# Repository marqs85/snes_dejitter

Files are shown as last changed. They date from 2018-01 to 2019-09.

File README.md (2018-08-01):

NES/SNES 240p de-jitter mod
==============

snes_dejitter is a mod board which eliminates sync jitter of NES/SNES 240p modes. Technical description and discussion is found on [this](https://shmups.system11.org/viewtopic.php?f=6&t=61285) thread.

Requirements for building the board and CPLD firmware
--------------------------------------------------------
* Hardware
  * [PCB](https://oshpark.com/shared_projects/NkuS1ju6) + [parts](pcb/bom/snes_dejitter.ods)

* Software
  * [Altera Quartus II version 13.0sp1 with MAX7000 support](http://dl.altera.com/13.0sp1/?edition=web)
  * [pof2jed](http://www.microchip.com/design-centers/programmable-logic/spld-cpld/tools/software/pof2jed) conversion tool
  * [ATMISP](http://www.microchip.com/design-centers/programmable-logic/spld-cpld/tools/software/atmisp) software
  * [WINE](https://www.winehq.org/) (if Windows OS is not used)

Requirements for flashing CPLD firmware
--------------------------------------------------------
* Hardware
  * OpenOCD supported JTAG programmer (e.g. FT2232 based)

* Software
  * [OpenOCD](http://openocd.org/)
  * Telnet client

CPLD image build procedure
--------------------------------------------------------

**NOTE:** Only needed when building a custom firmware. Pre-built images can be found under output_files/ on master and nes-fix (recommended for NES/FC) branches.

1. Open the project file in Quartus, and run compilation

2. Convert MAX7000 targeted POF object file into JEDEC file suitable for 1502AS via winpof2jed.exe:
~~~~
1. Select .pof file from previous step as input file
2. Select 1502AS as device
3. Change the following options:
  * Reduce MC power -> On
  * Open Collector -> Off
  * JTAG mode -> On
  * Slew rate -> Slow
4. Click "Run"
~~~~
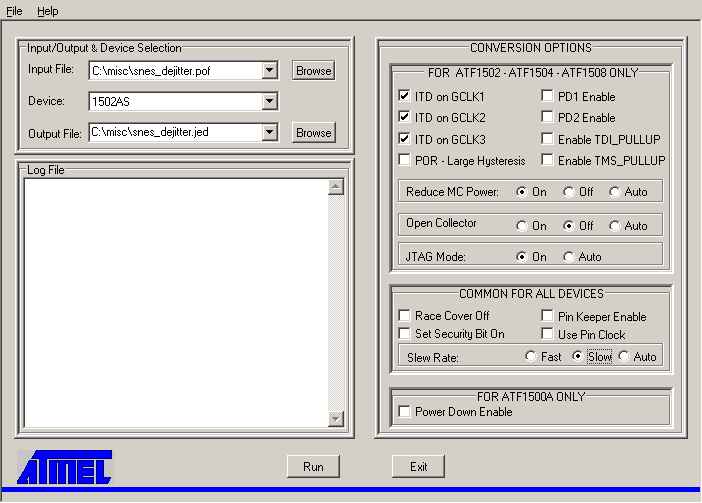
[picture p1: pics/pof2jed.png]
pof2jed


3. Convert JED to SVF via ATMISP:
~~~~
1. Create a new device chain via File->New
2. Set number of devices to 1
3. Set device to ATF1502AS
4. Set JTAG instruction to "Program/Verify"
5. Select .jed file from previous step as JEDEC file
6. Click "OK"
7. Tick "Write SVF file" and click "Run"
~~~~
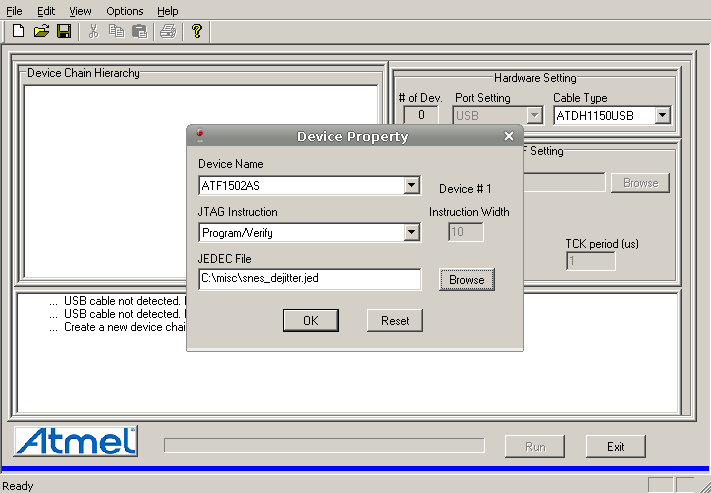
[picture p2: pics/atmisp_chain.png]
atmisp1

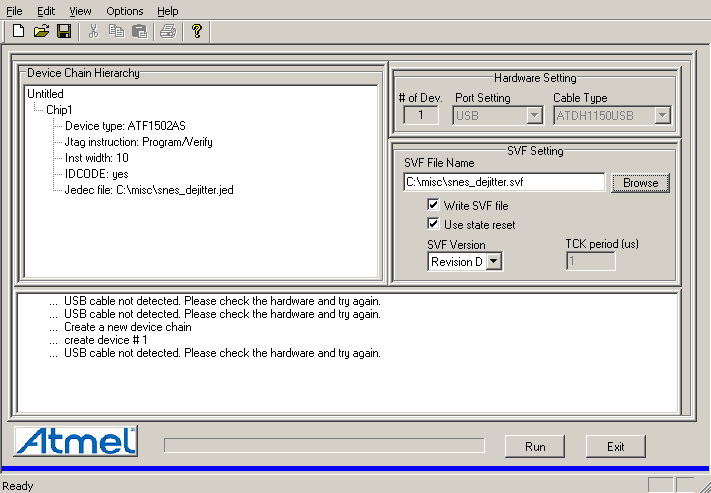
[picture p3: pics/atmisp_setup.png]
atmisp1


Board flashing
--------------------------------------------------------
The board can be flashed using any OpenOCD supported JTAG programmer that supports 3.3V-5V IO signal level (TCK, TMS and TDI are TTL inputs with 10k pull-downs). If 3.3V IO is used, JP4 (on v1.3 PCB) should be closed which clamps TDO output to 3.3V. A standalone snes_jitter board is flashed by hooking all of its 6 JTAG header pins to respective pins of the programmer/cable, and by running flash procedure specified below. After the board has been installed to NES/SNES, firmware can be subsequently updated, but in this method 5V pin of the JTAG connector MUST be left disconnected, and programming needs to be done while NES/SNES is powered on (without a game is ok). The update procedure is similar in both cases:

1. Create openocd.conf that matches your JTAG programmer. A configuration file for FT2232-based programmers is found in installation/openocd-ft2232.conf, and it uses following standard pinout for data signals:

Board pin | Programmer pin
--------- | -------------
TCK       | ADBUS0
TMS       | ADBUS3
TDI       | ADBUS1
TDO       | ADBUS2

2. After hooking up JTAG cable, initiate JTAG connection:
~~~~
openocd -f openocd.conf
~~~~
3. OpenOCD auto-probing should report a TAP controller with id 0x0150203f - if not, check connections and configuration. When successful, open another terminal to interact with openocd and program the chip:
~~~~
telnet localhost 4444
> svf <full_path_to_svf_file>
~~~~
4. The programming procedure should finish with no error, after which you can finish installation by powering off hardware and disconnecting the programmer.

Installation
--------------------------------------------------------
General descriptions on board pins are in table below. Model-specific installation instructions are added to separate <a href="installation/">subdirectories</a>.

Board pin  | Description
---------- | -------------
CSYNC_i    | TTL C-sync signal from the console
MCLK_EXT_i | External clock input. Used only in PAL mode, not needed in pure NTSC installations.
CLK_SEL_i  | Master clock source selection (0=internal/NTSC, 1=external/PAL). In PAL mode, MCLK and CSYNC are bypassed to output. Pin is pulled low internally, so it can be left disconnected in pure NTSC installations. Connected to PALMODE in multiregion installations. Can be forced high by bridging JP1 (pre-1.2 boards only), but must never be done if the pin is wired to console.
MCLK_o     | Clock output. An optional voltage divider (R13,R14 / JP2) can be used to reduce output level from ~4Vpp to ~3Vpp, see model-specific instructions for more details.
CSYNC_o    | C-sync output (~2.5Vpp unterminated, ~1.1Vpp into 75ohm termination) to an isolated multi-AV pin. Driver circuit is identical to SHVC-CPU-01. JP3 connects optional 330pF output capacitor that may not be present on console mainboard (not strictly needed, reduces potential noise at the price of less sharp transition time), see model-specific instructions for more details.

Jumper  | Description
------- | -------------
JP1     | Forces CLK_SEL_i high. Removed on v1.2 since it was mostly for debugging purposes.
JP2     | Enables MCLK_o voltage divider. Recommended for NES installations to ensure signal level is safe for NESRGB.
JP3     | Connects optional 330pF output capacitor on CSYNC_o.
JP4     | Enable TDO voltage clamp. Recommended if board is flashed with a 3.3V programmer.

PCB revision history
--------------------------------------------------------
### v1.3
* change (R9,R10) voltage divider values
* replace TDO voltage divider with an optional zener clamp (selectable via JP4)
* add R15 pulldown to prevent floating input pin

### v1.2
* remove JP1
* add JP2 and JP3 to easily support different setups

### v1.1
* change R14 value
* change JTAG connector

### v1.0
* first revision

FAQ
--------------------------------------------------------
### Can I buy the board pre-assembled / pre-installed
* VGP [store](https://www.videogameperfection.com/products/snes-jitter-kit/) offers pre-assembled boards with optional installation service.

### Can I flash the board with USB Blaster?
* USB Blaster is compatible with OpenOCD, but you have to check your programmer details (official/clone, 5V compatibility) and hook up and configure it accordingly. Official USB Blaster has fixed 6MHz TCK frequency which is probably too high for the board, so USB Blaster II and clones are more likely to work. None of the USB Blasters supply voltage on the board, but instead require connection from the board's supply to Vcc(TRGT) pin of the debug connector. You must thus power the board externally and connect 5V to Vcc(TRGT) (make sure your programmer supports 5V operation!). Some clones also require hacks on OpenOCD to operate correctly, see the [thread](https://shmups.system11.org/viewtopic.php?f=6&t=61285) for more details.

### Which other programmers can I use?
* OpenOCD supports a wide range of [debug adapters](http://openocd.org/doc/html/Debug-Adapter-Hardware.html). Several people also have programmed their boards using a Raspberry Pi. Instructions and tools for RPI can be found on the [thread](https://shmups.system11.org/viewtopic.php?f=6&t=61285).

### Does the mod change game speed in any way?
* Yes, but in very minimal way - in 1 hour of gameplay a de-jittered system falls less than 2 frames behind a vanilla system.

### Is it possible to disable de-jitter functionality after installation?
* When the board is installed so that MCLK_EXT_i and CLK_SEL_i are not used, a simple bypass can be added without firmware modifications. To do that, connect MCLK_EXT_i to CPLD pin 34 (MCLK_XTAL_o) and add a ON-OFF switch that connects MCLK_SEL_i to 5V.

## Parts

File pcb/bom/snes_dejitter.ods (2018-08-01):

Id | Designator | Package | Quantity | Designation | Supplier and ref | Alt. Supplier
1 | C1 | SM0603_Capa_libcms | 1 | 10u | https://www.digikey.fi/product-detail/en/murata-electronics-north-america/GRM188R60J106ME47D/490-3896-1-ND/965938 | https://www.mouser.fi/ProductDetail/581-06036D106MAT2A
2 | C2,C3,C4,C7 | SM0603_Capa_libcms | 4 | 0.1u | https://www.digikey.fi/product-detail/en/kemet/C0603C104K9RAC7867/399-15351-1-ND/7386749 | https://www.mouser.fi/ProductDetail/77-VJ0603Y104JXJPBC
3 | C5,C6 | SM0603_Capa_libcms | 2 | 12p | https://www.digikey.fi/product-detail/en/yageo/CC0603FRNPO9BN120/311-3885-1-ND/8024974 | https://www.mouser.fi/ProductDetail/77-VJ0603A120FXQCBC
4 | C8 | SM0603_Capa_libcms | 1 | 330p | https://www.digikey.fi/product-detail/en/murata-electronics-north-america/GCM1885C1H331FA16D/490-16420-1-ND/7363402 | https://www.mouser.fi/ProductDetail/80-C0603C331J5G
5 | Q1 | SOT-23_Handsoldering | 1 | 2SC2412 | https://www.digikey.fi/product-detail/en/rohm-semiconductor/2SC2412KT146R/2SC2412KT146RCT-ND/650652 | https://www.mouser.fi/ProductDetail/ROHM-Semiconductor/2SC2412KT146R
6 | R1,R2,R3,R6,R15 | SM0603_Resistor_libcms | 5 | 10k | https://www.digikey.fi/product-detail/en/susumu/RR0816P-103-D/RR08P10.0KDCT-ND/432748 | https://www.mouser.fi/ProductDetail/754-RR0816P-103D
7 | R8,R9 | SM0603_Resistor_libcms | 2 | 1k | https://www.digikey.fi/product-detail/en/yageo/RC0603FR-071KL/311-1.00KHRCT-ND/729790 | https://www.mouser.fi/ProductDetail/754-RR0816P-102D
8 | R10 | SM0603_Resistor_libcms | 1 | 5.6k | https://www.digikey.fi/product-detail/en/bourns-inc/CR0603-FX-5601ELF/CR0603-FX-5601ELFCT-ND/4247814 | https://www.mouser.fi/ProductDetail/Bourns/CR0603-FX-5601ELF
9 | R7 | SM0603_Resistor_libcms | 1 | 1M | https://www.digikey.fi/product-detail/en/yageo/AC0603FR-071ML/311-1MLDCT-ND/2828141 | https://www.mouser.fi/ProductDetail/603-RT0603FRE071ML
10 | R11,R14 | SM0603_Resistor_libcms | 2 | 300 | https://www.digikey.fi/product-detail/en/yageo/RC0603FR-07300RL/311-300HRCT-ND/726133 | https://www.mouser.fi/ProductDetail/754-RR0816P-301D
11 | R12 | SM0603_Resistor_libcms | 1 | 100 | https://www.digikey.fi/product-detail/en/vishay-dale/CRCW0603100RFKEA/541-100HCT-ND/1179695 | https://www.mouser.fi/ProductDetail/594-MCT06030C1000FP5
12 | R4,R13 | SM0603_Resistor_libcms | 2 | 39 | https://www.digikey.fi/product-detail/en/vishay-dale/CRCW060339R0FKEA/541-39.0HCT-ND/1179647 | https://www.mouser.fi/ProductDetail/603-RT0603DRE0739RL
13 | Y1 | Crystal_HC49-U_Vertical | 1 | 21.477272MHz | https://www.digikey.fi/products/en?keywords=HC49US-21.47727MABJ-UB | https://www.mouser.fi/ProductDetail/695-HC49US-214-U
14 | U1 | TQFP-44_10x10mm_Pitch0.8mm_Handsoldering | 1 | ATF1502AS-7AX44 | https://www.digikey.fi/products/en?keywords=ATF1502AS-7AX44 | https://www.mouser.fi/ProductDetail/556-AF1502AS7AX44
15 | J1 | JTAG_Header_Angled_1x06_Pitch2.54mm | 1 | JTAG_CONN | https://www.digikey.fi/product-detail/en/sullins-connector-solutions/PPPC061LGBN-RC/S5481-ND/775939
16 | D1 | SOD-323_Handsoldering | 1 | Zener_3v3 | https://www.digikey.fi/product-detail/en/diodes-incorporated/MMSZ5226BS-7-F/MMSZ5226BS-FDICT-ND/804906 | https://www.mouser.fi/ProductDetail/Diodes-Incorporated/MMSZ5226BS-7-F

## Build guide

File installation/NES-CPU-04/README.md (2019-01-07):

NES-CPU-04 installation guide
==============

(from [Retro Modding Wiki](https://www.retromodwiki.com/wiki/NES_dejitter_mod))

Steps

1. Remove C44, C45, and X1 from the NES motherboard
2. Connect a jumper wire between the pads of C44 and C45 as illustrated below.
3. Short JP2 and JP3 on snes_dejitter board
4. Cover copper areas on the bottom of snes_dejitter with electrical tape
5. Attach snes_dejitter on the bottom of NESRGB adapter board via double-sided adhesive tape
6. Connect 5V, GND and CSYNC_i to respective pads on NESRGB board (CSYNC_i -> CS# with NESRGB jumper J8 open)
7. Connect MCLK_o as shown in the picture and CSYNC_o to AV connector (possibly via 470ohm series resistor depending on your cable and preference). For MCLK_o, it is recommended to use a coax cable of which shield is connected to nearest GND in both ends
8. If the board has been flashed with default firmware, update it to [NES-tailored svf](https://github.com/marqs85/snes_dejitter/raw/nes-fix/output_files/snes_dejitter.svf) from nes-fix branch

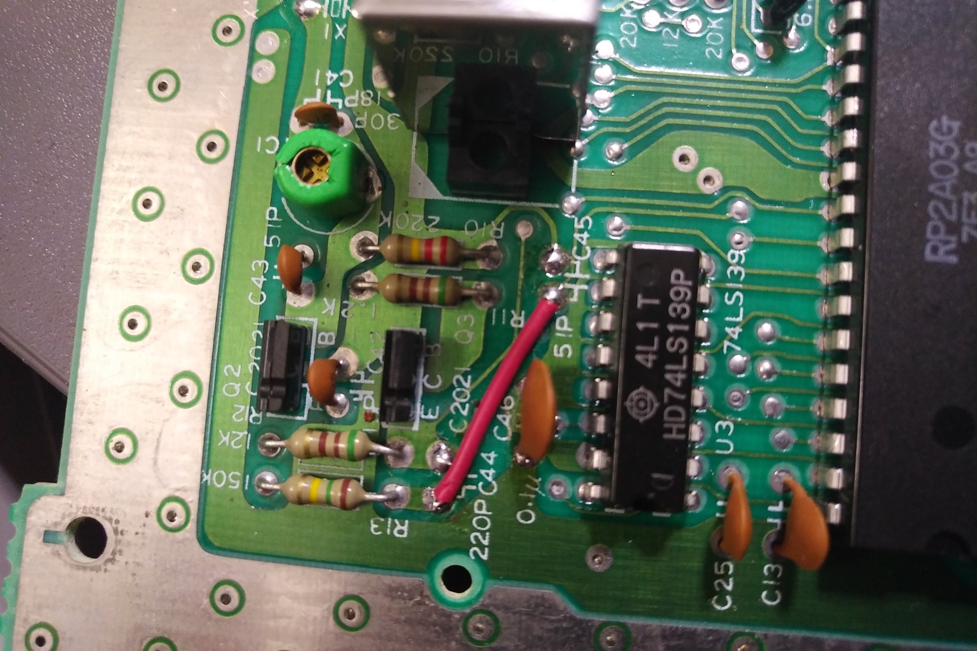
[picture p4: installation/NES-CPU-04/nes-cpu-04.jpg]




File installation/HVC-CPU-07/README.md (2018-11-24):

HVC-CPU-07 installation guide
==============

Steps

1. Desolder C4, C9 and (optionally) XTAL from Famicom mainboard
2. Add a jumper wire between C4 & C9 pads on CPU/PPU sides as shown in the picture below (ignore wires outside of red highlight circle)
3. Short JP2 and JP3 on snes_dejitter board
4. Cover copper areas on the bottom of snes_dejitter with electrical tape
5. Attach snes_dejitter on the bottom of NESRGB adapter board via double-sided adhesive tape
6. Connect 5V, GND and CSYNC_i to respective pads on NESRGB board (CSYNC_i -> CS# with NESRGB jumper J8 open)
7. Connect MCLK_o as shown in the picture and CSYNC_o to AV connector (possibly via 470ohm series resistor depending on your cable and preference). For MCLK_o, it is recommended to use a coax cable of which shield is connected to nearest GND in both ends
8. If the board has been flashed with default firmware, it's recommended to update it to [NES-tailored svf](https://github.com/marqs85/snes_dejitter/raw/nes-fix/output_files/snes_dejitter.svf) from nes-fix branch

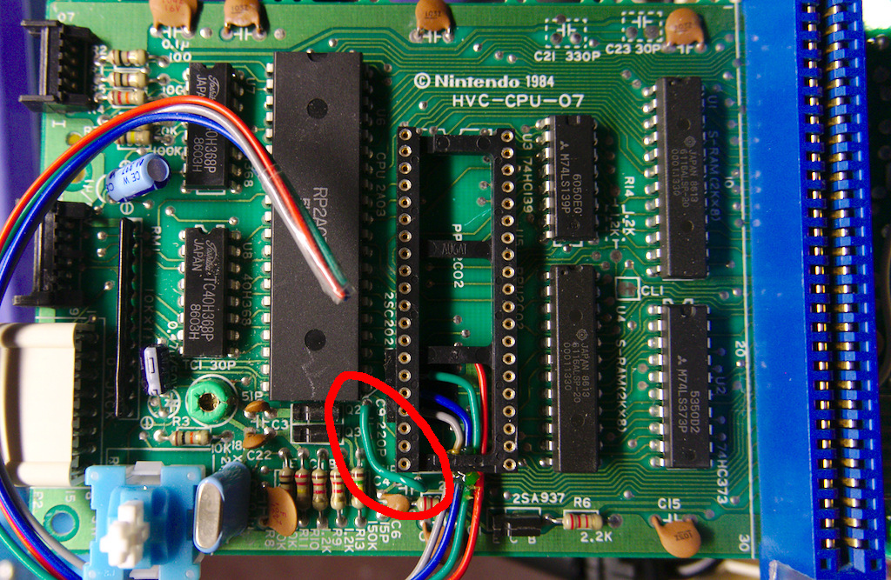
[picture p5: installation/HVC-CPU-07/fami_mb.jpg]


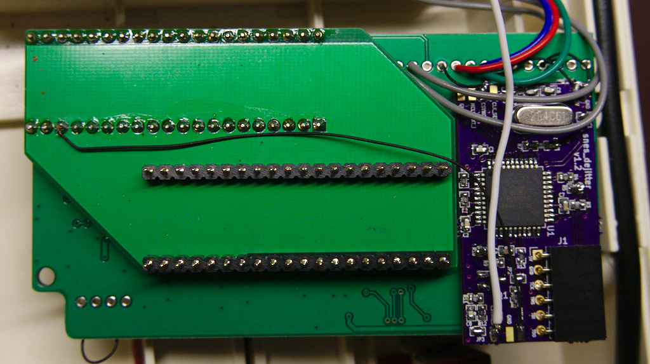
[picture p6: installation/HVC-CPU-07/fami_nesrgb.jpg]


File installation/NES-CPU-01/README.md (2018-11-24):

NES-CPU-01 installation guide
==============

(from [Retro Modding Wiki](https://www.retromodwiki.com/wiki/NES_dejitter_mod))

Steps

1. Remove C44, C45, and X1 from the NES motherboard
2. Connect a jumper wire between the outside pads of C44 and C45
3. Short JP2 and JP3 on snes_dejitter board
4. Cover copper areas on the bottom of snes_dejitter with electrical tape
5. Attach snes_dejitter on the bottom of NESRGB adapter board via double-sided adhesive tape
6. Connect 5V, GND and CSYNC_i to respective pads on NESRGB board (CSYNC_i -> CS# with NESRGB jumper J8 open)
7. Connect MCLK_o as shown in the picture and CSYNC_o to AV connector (possibly via 470ohm series resistor depending on your cable and preference). For MCLK_o, it is recommended to use a coax cable of which shield is connected to nearest GND in both ends
8. If the board has been flashed with default firmware, update it to [NES-tailored svf](https://github.com/marqs85/snes_dejitter/raw/nes-fix/output_files/snes_dejitter.svf) from nes-fix branch







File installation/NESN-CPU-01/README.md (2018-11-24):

NESN-CPU-01 installation guide
==============

(from [Retro Modding Wiki](https://www.retromodwiki.com/wiki/NES_dejitter_mod))

Steps

1. Remove C10 and X1 from the NES motherboard
2. Short JP2 and JP3 on snes_dejitter board
3. Cover copper areas on the bottom of snes_dejitter with electrical tape
4. Attach snes_dejitter on the bottom of NESRGB adapter board via double-sided adhesive tape
5. Connect 5V, GND and CSYNC_i to respective pads on NESRGB board (CSYNC_i -> CS# with NESRGB jumper J8 open)
6. Connect MCLK_o as shown in the picture and CSYNC_o to AV connector (possibly via 470ohm series resistor depending on your cable and preference). For MCLK_o, it is recommended to use a coax cable of which shield is connected to nearest GND in both ends
7. If the board has been flashed with default firmware, update it to [NES-tailored svf](https://github.com/marqs85/snes_dejitter/raw/nes-fix/output_files/snes_dejitter.svf) from nes-fix branch







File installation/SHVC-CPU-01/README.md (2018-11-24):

SHVC-CPU-01 installation guide
==============

Features

* single MCLK provided by snes_dejitter
* de-jittered CSYNC on multi-AV pin 3 (compatible with RGB cables wired to use CSYNC)

Steps

1. Desolder C5, R6 and R25 on SNES mainboard
2. Leave JP3 open on snes_dejitter board (rev v1.0/v1.1: leave C8 unpopulated)
3. Short JP2 on snes_dejitter board (v1.2 and higher revisions only)
4. Cover copper areas on the bottom of snes_dejitter with electrical tape
5. Attach snes_dejitter on the bottom of SNES mainboard via double-sided adhesive tape
6. Connect 5V, GND, CSYNC_i, CSYNC_o and MCLK_o as shown in image below

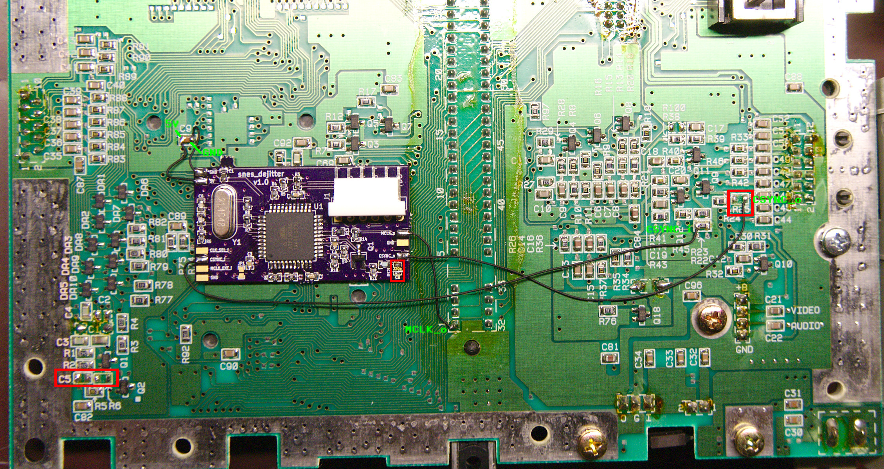
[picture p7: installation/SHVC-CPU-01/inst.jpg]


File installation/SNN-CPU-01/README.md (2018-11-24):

SNN-CPU-01 installation guide
==============

Features

* single MCLK provided by snes_dejitter
* de-jittered CSYNC on multi-AV pin 3 (compatible with RGB cables wired to use CSYNC)

Steps

1. Remove X1 and C3 from SNES mainboard
2. Leave JP2 open and close JP3 on snes_dejitter board (rev v1.0/v1.1: leave R14 unpopulated)
3. Cover copper areas on the bottom of snes_dejitter with electrical tape
4. Attach snes_dejitter on the bottom of SNES mainboard via double-sided adhesive tape
5. Connect 5V, GND and MCLK_o as shown in image below. CSYNC_i can be tapped from pin 7 of S-RGB, and CSYNC_o should be directly wired to pin 3 of multi-AV.

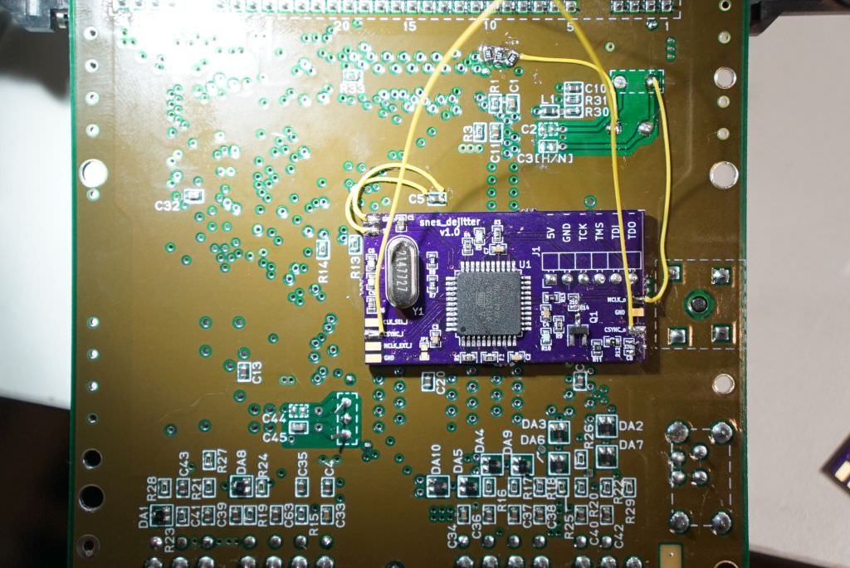
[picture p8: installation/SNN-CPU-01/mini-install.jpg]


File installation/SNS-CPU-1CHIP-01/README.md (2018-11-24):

SNS-CPU-1CHIP-01 installation guide
==============

Features

* single MCLK provided by snes_dejitter
* de-jittered CSYNC on multi-AV pin 3 (compatible with RGB cables wired to use CSYNC)

Steps

1. Remove X1, C3 and R12 from SNES mainboard
2. Leave JP2 and JP3 open on snes_dejitter board (rev v1.0/v1.1: leave C8 and R14 unpopulated)
3. Cover copper areas on the bottom of snes_dejitter with electrical tape
4. Attach snes_dejitter on the bottom of SNES mainboard via double-sided adhesive tape
5. Connect 5V, GND, CSYNC_i, CSYNC_o and MCLK_o as shown in image below

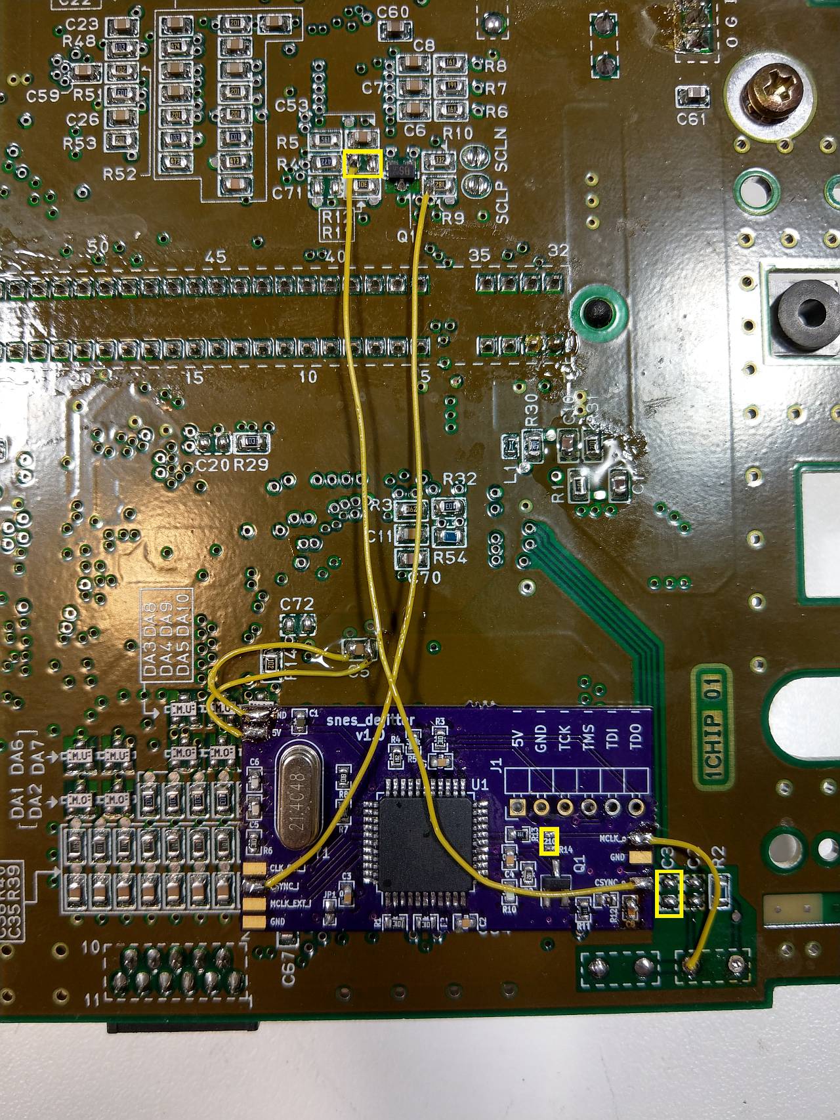
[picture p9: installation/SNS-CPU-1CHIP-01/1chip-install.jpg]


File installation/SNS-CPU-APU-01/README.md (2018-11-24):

SNS-CPU-APU-01 installation guide
==============

Features

* single MCLK provided by snes_dejitter
* de-jittered CSYNC on multi-AV pin 3 (compatible with RGB cables wired to use CSYNC)

Steps

1. Remove R12, R17 and R55 from SNES mainboard
2. Leave JP3 open on snes_dejitter board (rev v1.0/v1.1: leave C8 unpopulated)
3. Short JP2 on snes_dejitter board (v1.2 and higher revisions only)
4. Cover copper areas on the bottom of snes_dejitter with electrical tape
5. Attach snes_dejitter on the bottom of SNES mainboard via double-sided adhesive tape
6. Connect 5V, GND, CSYNC_i, CSYNC_o and MCLK_o as shown in image below

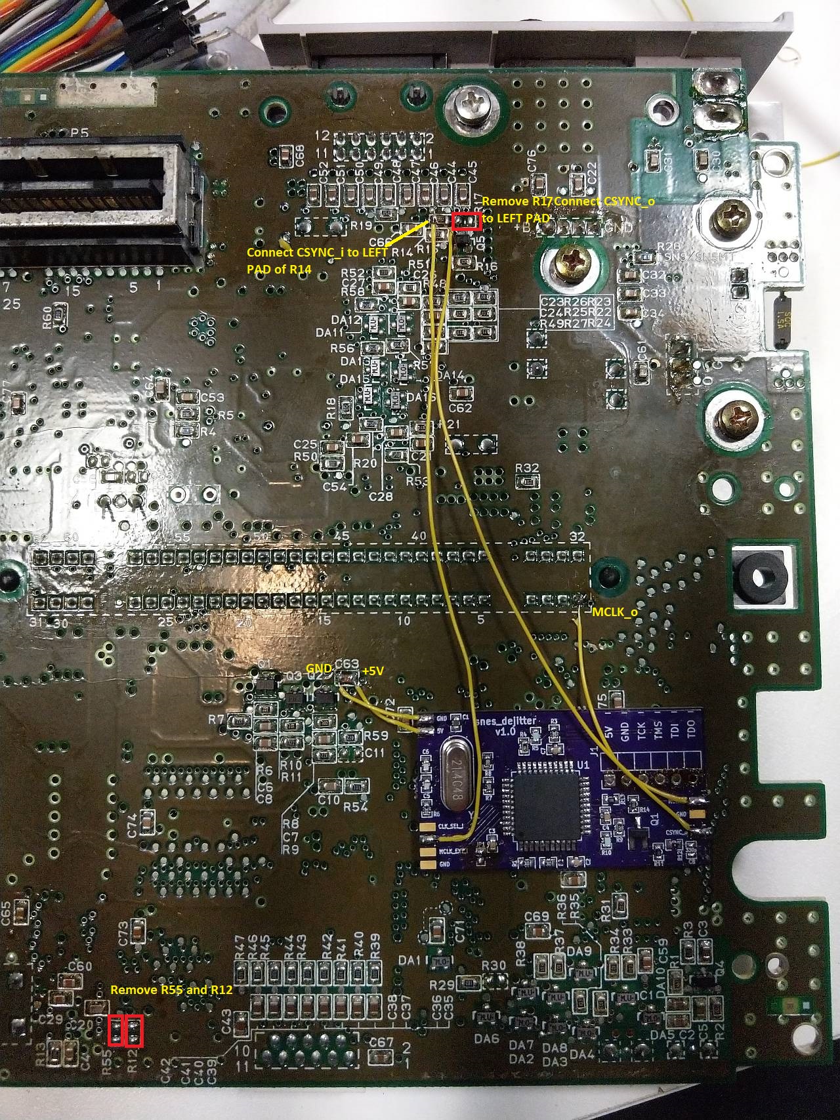
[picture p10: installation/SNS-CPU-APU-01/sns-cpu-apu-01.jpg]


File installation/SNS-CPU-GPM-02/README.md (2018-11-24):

SNS-CPU-GPM-02 installation guide
==============

Features

* single MCLK provided by snes_dejitter
* de-jittered CSYNC on multi-AV pin 3 (compatible with RGB cables wired to use CSYNC)

Steps

1. Remove R4, R5 and R25 from SNES mainboard
2. Leave JP3 open on snes_dejitter board (rev v1.0/v1.1: leave C8 unpopulated)
3. Short JP2 on snes_dejitter board (v1.2 and higher revisions only)
4. Cover copper areas on the bottom of snes_dejitter with electrical tape
5. Attach snes_dejitter on the bottom of SNES mainboard via double-sided adhesive tape
6. Connect 5V, GND, CSYNC_i, CSYNC_o and MCLK_o as shown in image below

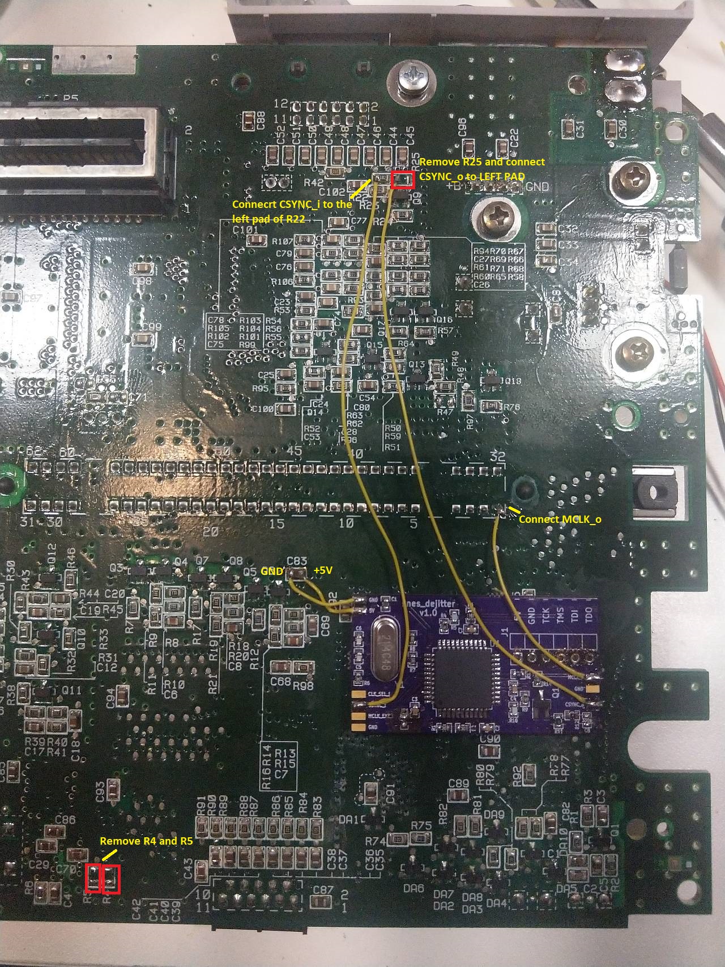
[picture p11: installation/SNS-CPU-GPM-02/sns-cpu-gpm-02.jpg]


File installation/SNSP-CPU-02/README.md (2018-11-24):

SNSP-CPU-02 installation guide
==============

Features

* dual MCLK for 50/60Hz modded console provided by snes_dejitter/S-CLK depending on mode
* de-jittered CSYNC on multi-AV pin 7 (compatible with RGB cables wired to use luma as sync)

Steps

1. Desolder R73 and R25 on SNES mainboard
2. Leave JP3 open on snes_dejitter board (rev v1.0/v1.1: leave C8 unpopulated)
3. Short JP2 on snes_dejitter board (v1.2 and higher revisions only)
4. Cover copper areas on the bottom of snes_dejitter with electrical tape
5. Attach snes_dejitter on the bottom of SNES mainboard via double-sided adhesive tape
6. Connect 5V and GND to C92
7. Connect CSYNC_i to S-ENC pin 8 (or S-PPU2 pin 100)
8. Connect CSYNC_o to multiAV pin 7
9. Connect MCLK_o to CPU side of removed R73
10. Connect MCLK_EXT_i to S-CLK side of R73
11. Connect CLK_SEL_i to 50/60Hz select line (same that goes to S-PPU1 pin 24)

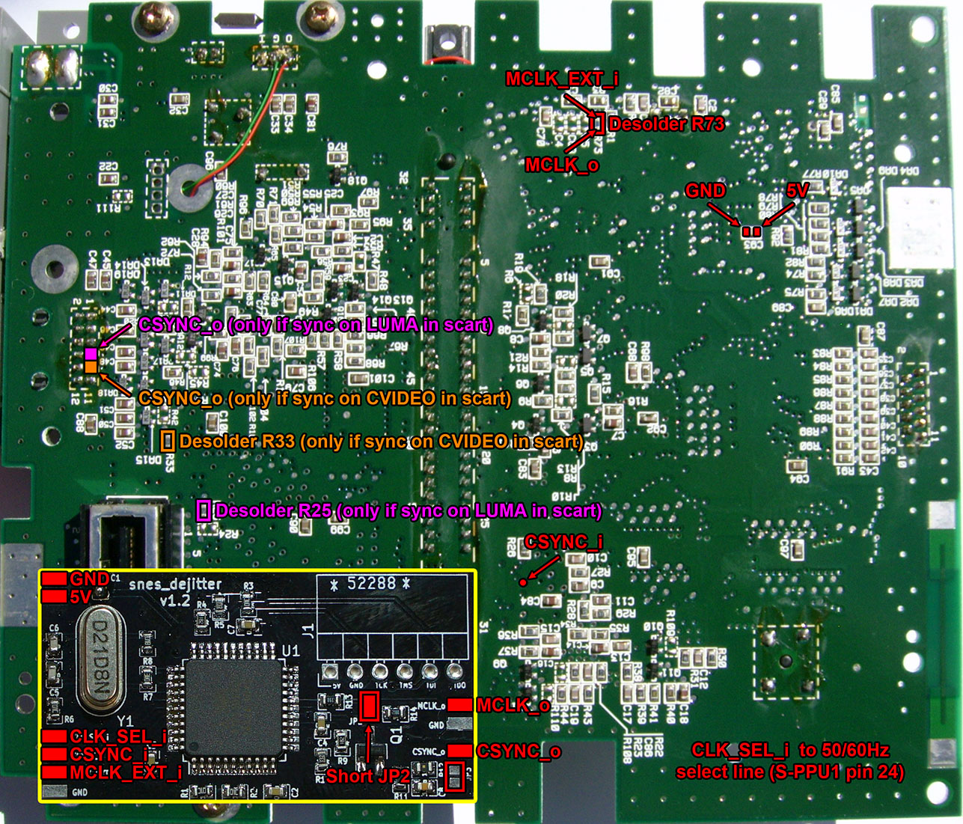
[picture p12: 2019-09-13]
installation/SNSP-CPU-02/PAL_snes_dejitter_diagram.jpg

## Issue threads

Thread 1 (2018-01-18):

Missing Kicad Libraries

Helder1981, 2018-01-18:
Hello I tried to open the schematic and got these 2 errors:

**The following libraries were not found:**
snes_dejitter-rescue
motors

Is there anyway you can also have a BOM list to build the board and any chance you can make this in Eagle CAD?

Thanks.

marqs85, 2018-01-21:
BOM is added in facaa83. You should be able to ignore missing library errors as long as no components are actually used from them (like in case of those 2).

As for redoing the board in Eagle, it's a bit tall order considering required work versus benefits. There should be some conversion tools avaiable for those who want to import the design into Eagle, and many of those who want to integrate functionality into their design will probably want to make own schematics and layout anyway.

Closed 2018-01-21.

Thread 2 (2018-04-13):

Error programming chip

matjolic, 2018-04-13:
In the process of flashing the chip I am running into an error:

`BUG: RUN/IDLE -> ??? isn't a valid TAP transition`

I am using the Adafruit FTDI Friend which seems to launch correctly:

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

These are the last lines from the console after I launch svf <path to svf file>

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

marqs85, 2018-04-14:
Did you generate the svf yourself or use snes_dejitter.svf from output_files/?

matjolic, 2018-07-25:
Just wanted to followup on this issue, I think I found the cause for this. The Adafruit FTDI friend uses the FT232R chip which has a clock timing issue when trying to bit-bang a chip. This is best explained in this blog post by Scott Harden: [link](https://www.swharden.com/wp/2018-06-03-bit-bang-ftdi-usb-to-serial-converters-to-drive-spi-devices/)

I was able to use a Raspberry Pi's GPIO pins with OpenOCD to succesfully flash one board following [this post](https://movr0.com/2016/09/02/use-raspberry-pi-23-as-a-jtagswd-adapter/) linked by ebeb on the shmups forums. Thanks for that!

I have since acquired and FT2232H breakout board which doesn't have the issue mentioned above. Hope this clears out any confusion for future folks ;)

Closed 2018-07-25.

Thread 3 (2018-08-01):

NES-001 Everdrive N8 crash

matjolic, 2018-08-01:
I installed the dejitter board in a NESRGB modded NES-001. I get this weird behavior where the game hangs either a few minutes in or at the loading screen and sometimes even resets the Everdrive N8. If I remove the dejitter board, the same game runs fine. Specifically, I was trying an expansion audio game, VRC6 Akumajou Densetsu. I haven't tried the comparison with other games, but I was able to replicate this behavior on a second system. I've tried both the original firmware and the nes-fix firmware. Is the N8 somehow relying on the original crystal? Does expansion audio rely on it? I am not savvy enough to answer these questions, can someone replicate this?

marqs85, 2018-11-24:
Updated instructions with a recommendation to use coax cable (both sides grounded) for MCLK_i which should fix the issue based on posts on the forum thread.

Closed 2018-11-24.

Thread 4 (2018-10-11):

SNSP-CPU-02

danxster, 2018-10-11:
I have a SNSP-CPU-02, I can't seem to find the solder points for this model.

Could someone please help out, I have a snes_dejitter 1.3?

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

marqs85, 2018-10-11:
Looking at [this](https://console5.com/wiki/File:PAL-SNES_Schematic.pdf) schematic, you'd need to first desolder R73 and either R33 (sync on CVBS) or R25 (sync on luma) depending on the RGB cable you use. After that:

-CSYNC_i is connected to S-ENC pin 8
-CSYNC_o is connected to multiAV side of removed R33 / R25
-MCLK_o is connected to CPU side of removed R73
-5V and GND are connected to nearest place where you can get them easily

Since you seem to have region mod in place, you might want to keep PAL mode as close to 50Hz as possible (which would otherwise be slightly off with NTSC MCLK). For that you'll need to additionally connect S-CLK side of R73 to MCLK_EXT_i and PAL selection pin (same that goes to S-PPU1 pin 24) to MCLK_SEL_i.

marqs85, 2018-10-14:
That looks ok, but I'd rotate the mod board by 180deg and move it left so that length of MCLK_o wire can be kept minimum. Now that I re-checked the schematic, CSYNC_o actually should be directly connected to multiAV pin7 (R25 must be still removed).

danxster, 2018-10-29:
I'm not getting any picture with the following configuration, any ideas?

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

marqs85, 2018-10-29:
On the upper pic, it seems you've hooked 5V and GND to C9 which is not a supply rail cap if you check the schematic. C92 should be good for that and is also closer. On the bottom pic, it looks you may have connected to pin 99 of PPU2 instead of 100 but the resolution is not high enough to say for sure. Similarly, pin 29 and 30 look shorted.

danxster, 2018-10-31:
Thanks for your help, its now function perfectly :-)

This is what I did to get it working:
5V and GND to C92
Connected to PPU2 on pin 100

marqs85, 2018-10-31:
Good to hear that. I noticed you've not connected CLK_SEL_i pin of the board which is OK in case you're fine with slightly off-50Hz refresh rate in PAL mode. If you connect it as described in my first reply, you'll get accurate 50Hz but in that case you shouldn't do 50/60 switching while running a game as clock muxing is not glitchless. Could you also take photos of completed installation so that I can create instructions for SNSP-CPU-02?

marqs85, 2018-11-24:
Added instructions for SNSP-CPU-02 based on this. Closing the issue.

Closed 2018-11-24.

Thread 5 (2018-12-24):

NES-CPU-04 different PCB layout + pink flickering on composite output from NESRGB

Quantum-cross, 2018-12-24:
I'm installing the de-jitter mod on an NES-CPU-04 and I had to use a multimeter and NES schematics to figure out which wires to bridge.

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

Everything seems to work right if I bridge the the points shown there (not the outside PTHs).

The only other problem I am having is the composite video output from the NESRGB has some artifacts:
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

This seems to flicker every frame. This is present on an LCD tv too (not a capture problem) and RGB output also seems to work fine without that pink glitch.

marqs85, 2019-01-07:
instructions added

Closed 2019-01-07.

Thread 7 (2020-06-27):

Programming

Chris230291, 2020-06-27:
Hello. I am trying to program the chip using my clone usb blaster.
When I try to run the command this is what I am getting...

```
pi@raspberrypi:~ $ sudo openocd -f openocd/tcl/interface/altera-usb-blaster.cfg
Open On-Chip Debugger 0.10.0+dev-00430-g06123153 (2020-06-27-19:51)
Licensed under GNU GPL v2
For bug reports, read
        http://openocd.org/doc/doxygen/bugs.html
Warn : Adapter driver 'usb_blaster' did not declare which transports it allows; assuming legacy JTAG-only
Info : only one transport option; autoselect 'jtag'
Info : Listening on port 6666 for tcl connections
Info : Listening on port 4444 for telnet connections
Error: No lowlevel driver available
```

I am not sure what I can do to fix that.

I decided to try using the Quartus II programmer software in windows to see if that would work. I can get it to detect _something_, but its an unknown device (UNKOWN_150203F) and trying to flash using the  .pof file just gives errors.

I am supplying 5v to the board. Without it nothing is detected. I have also shorted R4.

Can anyone give me any advice. I am happy to use linux or windows. No pref

Cheers
Chris

marqs85, 2020-07-04:
It looks like the openocd version you're using is not built with usb blaster support (check lines 149 and 866 [here](http://openocd.org/doc/doxygen/html/usb__blaster_8c_source.html)). You might want to try building it from source and enable usb blaster support during configure (./configure --enable-usb-blaster).

Chris230291, 2020-07-04:
Thanks for the reply but I ended up just buying a ft232h which worked perfectly

Closed 2020-07-04.

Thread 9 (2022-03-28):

Flickering video for S-Video and Composite Video after DeJitter Mod

BambooShadow, 2022-03-28:
The Composite Video and S-Video signal seems to be somewhat compromised once the DeJitter Modboard is active.
The RGB-Signal is splendid and also the DeJitter-Mod is working perfectly. Line4x, Line5x with the OSSC, no problem!

I've noticed this a while ago, when installing a NESRGB (HW 2.0, FW 2.3) into an AV Famicom, with the DeJitter Modboard:
https://www.youtube.com/watch?v=jwfaHW9rPv4

And now again with borti's [SNES_MultiRegion_with_DeJitter_QID](https://github.com/borti4938/SNES_MultiRegion_with_DeJitter_QID). Installed into a PAL SNES 1Chip console (SNSP-CPU-1CHIP-01):
https://www.youtube.com/watch?v=WQlpZ9cdpdc

I don't think it's very important because most of these consoles will be ran with RGB-only for the most part. And since most users will use/install the DeJitter-Mod for the OSSC - and the OSSC can only accept RGB anyway - I guess few users noticed at all that Composite or S-Video is shaky.

But the SNES_MultiRegion_with_DeJitter_QID is a more universal mod which also easily allows to turn on/off the DeJitter feature by a toggle switch. So maybe more users could consider the toggle-switch, if they want to use 60Hz with Composite Video and S-Video. Then they could switch off DeJitter and enjoy without shakyness their 60Hz-console :).

Anyhow - I wanted to share this for documentation purposes.

marqs85, 2022-03-28:
The video encoder should be fed with a subcarrier generated from a stable clock to avoid these issues. Such signal is available from dejitter/multi board but the standard instructions may not describe that extra connection.

Also, have you tested if similar artefacts appear on a CRT?

BambooShadow, 2022-03-28:
Hi marqs, thanks for your quick response.

Yes, the artefacts also appear on a CRT (that's where I originally discovered them). Direct connection from console to device with decent & shielded video cables and the console is running with a proper, original power supply.

Borti also already suggested testing SJ63 on the SNES_MultiRegion_with_DeJitter_QID-Board. I left both jumpers open at first, so I'll mess around with them now, trying to fix the issue.

However, regarding the AV Famicom+NESRGB+DeJitter, I don't see an option to change the subcarrier, so that should be done automatically, if I understand it correctly.

The install was clean and RGB works properly.
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

Gonna report back, once I did some more testing with SJ63 on the PAL SNES 1chip with the borti-Board.

Thanks!

marqs85, 2022-03-28:
In both cases you need to lift video encoder subcarrier pin and connect a wire to it. Other end of the wire comes from
SNES: CClk.o pad on multi-board
NES: CPLD pin 11 on de-jitter board

BambooShadow, 2022-03-30:
So I did some further analysis, summarizing everything in this video (video-description!)
https://youtu.be/6uFcSpkLgLc

Gonna copy + paste the text from the description in here for archiving purposes:

_This is some further testing to find proper settings using a PAL SNES 1 Chip Console (SNSP-CPU-1CHIP-01) with borti's SNES_MultiRegion_with_DeJitter_QID Modboard.
I experienced problems, using the DeJitter-feature with Composite Video and S-Video.

However with some additions to the normal installation-process, one can get decent results, at least with S-Video. This can be achieved by the following additional steps:
1.) Move R4 to R62 on the Modboard
2.) Connect right pad of R4 to CClk.o
3.) Close SJ63.1 to output color carrier derived from non-dejittered clock

see also:
[https://i.imgur.com/RKbnugA.jpg](https://www.youtube.com/redirect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)

- I playtested a PAL cartridge (Yoshi's Island) in 50Hz then 60Hz mode
- I playtested an NTSC-J cartridge (Kirby Super Star) in 60Hz then 50Hz mode
- I tested also the 240p Test Suite (PAL / NTSC version) in 50Hz and 60Hz

You can see that the image problems only occur in 60Hz mode. 50Hz mode will work fine always (probably because the Dejitter-Feature only works for 60Hz modes).

[0:00](https://www.youtube.com/watch?v=6uFcSpkLgLc&t=0s) Composite Video, SJ63.2 closed*, DeJitter: ON
[10:09](https://www.youtube.com/watch?v=6uFcSpkLgLc&t=609s) S-Video, SJ63.2 closed*, DeJitter: ON
You can see here that whenever 60Hz-mode is used, there is some color distortion and flickering, especially on the top of the screen.

[19:37](https://www.youtube.com/watch?v=6uFcSpkLgLc&t=1177s) Composite Video, SJ63.1 closed**, DeJitter: ON
You can see here, that in 60Hz mode the color distortion is gone, but the image is still a little more flickery than it should be (compared to having DeJitter turned off).

[30:25](https://www.youtube.com/watch?v=6uFcSpkLgLc&t=1825s) S-Video, SJ63.1 closed**, DeJitter: ON
Again, color distortion is gone in 60Hz mode and the noisy flickering that we saw with Composite Video is also not present with S-Video!

[41:23](https://www.youtube.com/watch?v=6uFcSpkLgLc&t=2483s) Composite Video, SJ63.2 closed*, DeJitter: OFF
With the DeJitter-feature being turned of, there is no flickering (at least not more than usual amount you get from Composite Video) and no color distortion.

Since we most likely want to use and utilize the DeJitter-Feature though, my conclusion and recommendation would be to have the DeJitter feature turned on (leave SJ31 open!) and use the additional modification (moving R4 etc..) + closing SJ63.1.

*outputs color carrier derived from dejittered clock
**outputs color carrier derived from non-dejittered clock_

snowekim, 2022-12-14:
Is it possible to only Dejitter RGB but not composite/S-video?

marqs85, 2022-12-15:
The composite/s-video encoder should receive stable (subcarrier) clock and sync when connected as described earlier so I don't understand why distortion/flickering is present.

dptsolutions, 2023-06-19:
I believe I am suffering from this problem as well. I'm using the 1.3 version of the dejitter board, and it's installed on a Super Famicom w/ board revision SNS-CPU-GPM-02. I've followed the instructions as specified for this revision in the repo and the RGB works fine on my OSSC, but if I attempt to hook it up to my recently acquired CRT via composite, I get output problems, where colors are wrong at the top.

In an earlier comment, you said:

> In both cases you need to lift video encoder subcarrier pin and connect a wire to it. Other end of the wire comes from
SNES: CClk.o pad on multi-board (also remember to close one of the 2 jumpers)

But I am not sure I understand what this means. Can you help me find the pin? Using the [chip list](https://wiki.console5.com/wiki/SNES#SNS-CPU-GPM-02_(1993))) for this board revision, The video encoder is chip [U7](https://wiki.console5.com/wiki/BA6592F)([Pinout description](https://gamesx.com/wiki/lib/exe/fetch.php?media=schematics:pinout_s-enc.pdf)). Using this [pinout diagram](https://gamesx.com/wiki/lib/exe/fetch.php?media=schematics:pinout_s-enc.pdf), it looks like the chroma subcarrier input is pin 14.

Thus, is the fix for my revision:
1. Lift pin 14 on chip U7
2. Solder a wire from CClk.o on the dejitter board to the lifted pin

??

marqs85, 2023-06-19:
I revisited SNES schematics and noticed that S-ENC/S-RGB encoders are somewhat different to BH7236AF used in NESRGB and the subcarrier should not be directly connected to them. There is a small filter circuit between PPU and encoder input, so the subcarrier should be connected to input of the filter instead. In case of SNS-CPU-GPM-02, according to [this](https://wiki.superfamicom.org/uploads/snes_schematic_color.pdf) schematic you could remove R29, and connect CClk.o to the filter side pad of removed part thru 10k resistor (reusing R29 if you like).

dptsolutions, 2023-06-20:
Hey, thanks for the help! Looking at the schematic, I see what you're talking about, and I believe I understand what I need to do. Does this illustration look correct to you?
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

marqs85, 2023-06-21:
@dptsolutions on snes_dejitter board subcarrier is available on CPLD pin 11 (in the picture it's wired to csync output). CClk.o refers to a pad SNES_MultiRegion_with_DeJitter_QID board.

dptsolutions, 2023-06-26:
@marqs85 thanks for the double check, I appreciate it. Here's an updated image, do I have it correct now?

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

marqs85, 2023-06-27:
Yes, you just need to remove R29 and figure which pad is on the side of U7 (connected to R28).

TwistedTom, 2023-09-19:
I just looked at the code, it seems hooking up pin 11 to the S-ENC/S-RGB NTSC/PAL pin fixes the carrier to NTSC (3.58).
So using a switchable PAL/NTSC config (on a PAL 3-chip console), now NTSC composite/s-video will be ok but PAL broken.

If it was a 1-chip I could do MCLK_EXT_i/4 for (17.73/4=4.43) but for my 3-chip guess i'll have to add some extra circuitry to switch original 4.43 from S-CLK?

marqs85, 2023-09-19:
Yes, that would not work for PAL in a switchable system. On the other hand, you could just keep S-ENC/S-RGB in NTSC mode and see if your TV supports NTSC50 with PAL region games.

TwistedTom, 2023-09-19:
How about taking the 4.43 carrier from the S-CLK to a unused CPLD pin, then bypassing it to SC_o when switched to PAL (like MCLK_EXT_i is)?

Something like:
```
input PAL_car // an un-used pin
output SC_o   // not a reg now
...

reg SC_o_r;  // toggle this in original /6 block

assign SC_o = MCLK_SEL_i ? PAL_car : SC_o_r;
```

That should make PAL 3-chip work in both modes. PAL 1-chip should work in both modes already I think?
Perhaps this is more of a thing for the guys making the mod boards rather than snes_dejitter?

marqs85, 2023-09-20:
Sure, you could do it like that for PAL 3-chip. For PAL 1-chip a firmware modification alone would be sufficient.

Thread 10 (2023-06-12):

Installation instructions for the SNS-CPU-RGB-01 board

ttoffalori, 2023-06-12:
Hi,

what installation guide can I use for the SNS-CPU-RGB-01?
I checked the existing SNS guides, but they all look a bit different to my board.
Do you have a guide for this or can you assist me?

Thank you.

ttoffalori, 2023-06-12:
Hi marqs85, thank you very much for the fast response.

I am very sorry, but I do not understand what you mean. I checked the GPM-02 instructions, but to me it looks completely different.

Here is an image of my board and I highlighted the R4, R5 and R25. Do I still have to remove them?
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

marqs85, 2023-06-12:
Part codes probably match even though part placement is somewhat different, but to be sure you should check with a multimeter against [this](https://wiki.superfamicom.org/uploads/snes_schematic_color.pdf) schematic (see my questions above).

ttoffalori, 2023-06-12:
Your answer is highly appreciated. Unfortunately I am not skilled enough to answer this questions myself.
Is there any chance we can solve this together?

Then I could test and write a guide for this model number and add it to your instructions for other people.

marqs85, 2023-06-13:
I can only give instructions what to check, but for you'd need to test continuities with a multimeter. If the component numbers are match between revisions, you should see continuity between either end of of R4 and R5 and cartridge connector pin 1. Similarly there should be continuity between either end of R25 and multi-out pin 3.

ttoffalori, 2023-06-14:
OK that one I can check.
Might be a stupid question for you, but which pin exactly is the R25? :D

Thank you.

marqs85, 2023-06-14:
R25 refers to the component. It has 2 pins of which another one is most likely connected to multi-out pin 3. The point here is to check which one (or if neither) is.

ttoffalori, 2023-06-19:
Thanks marqs. I will try this next weekend.

toffalori, 2023-07-14:
> Thanks marqs. I will try this next weekend.

Update: Unfortunately I faced some other issues with my SNES, thats why I decided to not install this mod anymore.

From my side this issue can be closed.
Thanks again for all your help.

davedoc1984, 2025-01-31:
Hi, I have one of these boards and have noticed the same issue in that the components look the same as SNS-CPU-APU-01.

I have installed the board as per those instructions but I am still getting the "Jitter" with the OSSC. It works fine with my Framemeister.

To answer the questions above that marqs asked of the OP:

R25 on this board does not have continuity to Pin 3 of the Multi-Out. R14 Does.

Also R4 and R5 on this board does not have continuity to Pin 1 of the Cartridge slot.

marqs85, 2025-02-01:
Ok, so the board should not have differences compared to SNS-CPU-APU-01 in this context. Are you sure it's the jitter issue which causes OSSC not to sync with your TV? Do have any game using 480i (which natively does not have jitter) to see if this is the case? Also, which OSSC firmware version are you using?

marqs85, 2025-02-01:
It's worth trying out setting "ADC PLL BW" to Medium under sync opt (possibly with also "FPGA PLL BW" set to low). These options were recently added but the default value has reduced compatibility in some setups.

davedoc1984, 2025-02-01:
Hi Marqs :) that looks to have solved the issue for me! Thank You :).

Out of interest what do those 2 settings do?

marqs85, 2025-02-01:
They reduce PLL bandwidths and thus spread any disturbances time domain, resulting to better clock signal quality (but potentially higher sampling jitter). Was the sufficient to change the first setting or did you also need to lower FPGA PLL BW?

davedoc1984, 2025-02-01:
I did both settings but I can change the FPGA PLL BW back to where it was by default (which I think mine was set to High)?

marqs85, 2025-02-03:
You can try and see if it makes a difference.

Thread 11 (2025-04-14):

PAL 1chip snes with snesrgb and supercic fitting intstructions?

matvenu, 2025-04-14:
I have a PAL 1chip snes fitted with supercic and snesrgb.  I know that this mod isn't originally supported for PAL consoles, but it can be since it is modded with these boards.
I have seen some photos of people who did this already, but no clear info or photos on how to install it.

Searching around, I found some instructions but they seem to be vauge. No photos or schematics.

**Here’s the info for installing de-jitter on PAL SNES with SCIC. It’s been a while since I installed one of these, hope I haven’t forgotten anything.

    Remove X1, C3, R28 and D1 from SNES motherboard.
    Leave JP2 open
    Leave JP3 open
    Connect 5v and GND to regulator output or any other 5v and GND points.
    Connect MCLK_EXT_i to SCIC clock output
    Connect CSYNC_i to pin 7 of S-RGB chip or any via connected to that pin.
    Connect MCLK_o to left hand through hole of X1 (TC1+)
    Connect CSYNC_o to top pad of R28
    Connect CLK_SEL_i to SCIC mode pin_**

Is it possible to see a photo of this install or more detailed install instructions?

marqs85, 2025-04-15:
Not sure if it helps, but [here](https://circuit-board.de/forum/index.php/Attachment/213551-PAL-snes-1chip-schematic-pdf/) is schematic to SNSP-CPU-1CHIP-01/SNSP-CPU-1CHIP-02. For pictures you need to ask someone who has installed it into one of these.

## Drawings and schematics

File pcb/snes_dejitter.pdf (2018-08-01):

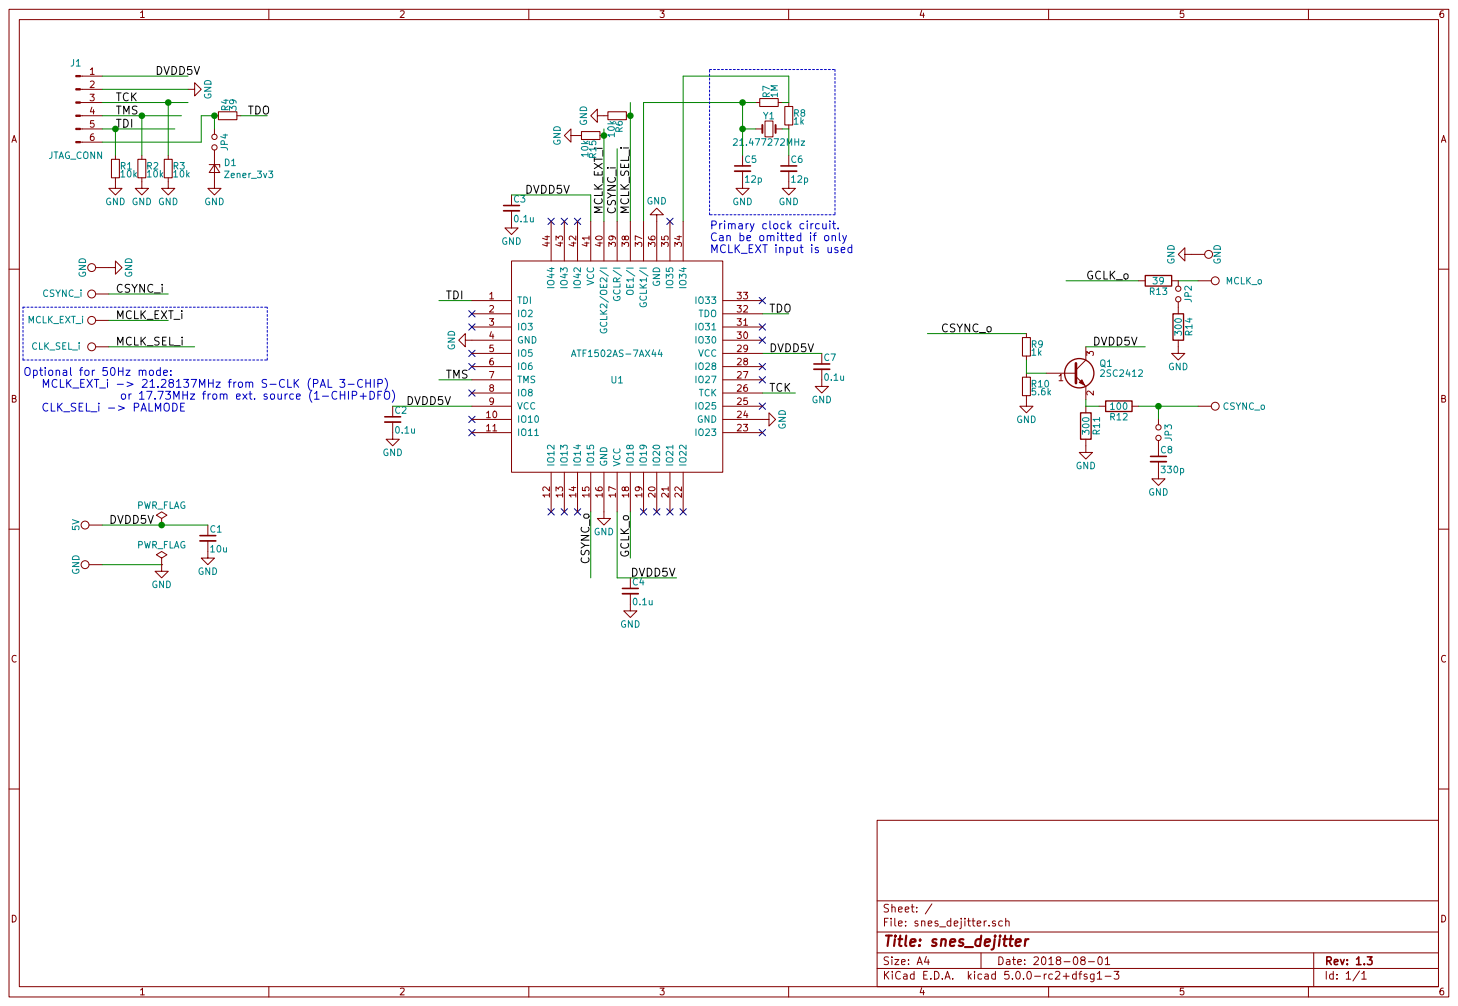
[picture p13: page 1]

CSYNC_o Primary clock circuit.
Can be omitted if only
MCLK_EXT input is used

Optional for 50Hz mode:
MCLK_EXT_i -> 21.28137MHz from S-CLK (PAL 3-CHIP)
CLK_SEL_i -> PALMODE

or 17.73MHz from ext. source (1-CHIP+DFO)

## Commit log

2018-01-21 PCB v1.1 with minor improvements
    [snes_dejitter-B.Cu.gbr, snes_dejitter-B.Mask.gbr, snes_dejitter-B.Paste.gbr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]
2018-01-22 add pdf schematic + SHVC-CPU-01 installation guide
2018-04-23 add v1.2 board revision
    [snes_dejitter-B.Cu.gbl, snes_dejitter-B.Mask.gbs, snes_dejitter-B.Paste.gbp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]
2018-05-29 update JED/SVF, add Famicom HVC-CPU-07 instruction
    [snes_dejitter.ods]
2018-07-29 add pcb v1.3 and update instructions
    [snes_dejitter-B.Cu.gbl, snes_dejitter-B.Mask.gbs, snes_dejitter-B.Paste.gbp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]
2018-08-01 pcb: replace TDO resistor divider with zener clamp
    [snes_dejitter-B.Cu.gbl, snes_dejitter-B.Mask.gbs, snes_dejitter-B.Paste.gbp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]
2020-03-17 output subcarrier on CPLD pin 11
